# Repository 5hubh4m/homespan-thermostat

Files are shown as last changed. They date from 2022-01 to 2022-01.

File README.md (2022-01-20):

# HomeSpan Thermostat

HomeKit connected smart thermostat based on Arduino using [HomeSpan](https://github.com/HomeSpan/HomeSpan).

## Background and Motivation

I have a 24 V Heat-only system with a 2-wire system (No C wire, only R and W). It used a manual
Honeywell single-point thermostat. I wanted to get the functionalities of a HomeKit compatible
smart thermostat without the hassle of installing a C wire myself and/or having to buy an
expensive smart thermostat. So I created my own with a Wi-Fi capable microcontroller.

## Hardware

I used a [Adafruit ESP32-S2 Feather](https://www.adafruit.com/product/5000) board, along with
a [TMP36](https://www.adafruit.com/product/165) analog temperature sensor, and a
[simple non-latching relay](https://www.adafruit.com/product/4409).

I wired up the TMP36 to an analog input pin (`A5` i.e `8`) and the relay to a digital pin (`10`),
and connected the relay to the R and W wires in my heating panel in the `NO` mode i.e when the relay is
`off`, the heater is also `off`. The circuit diagram is given below.

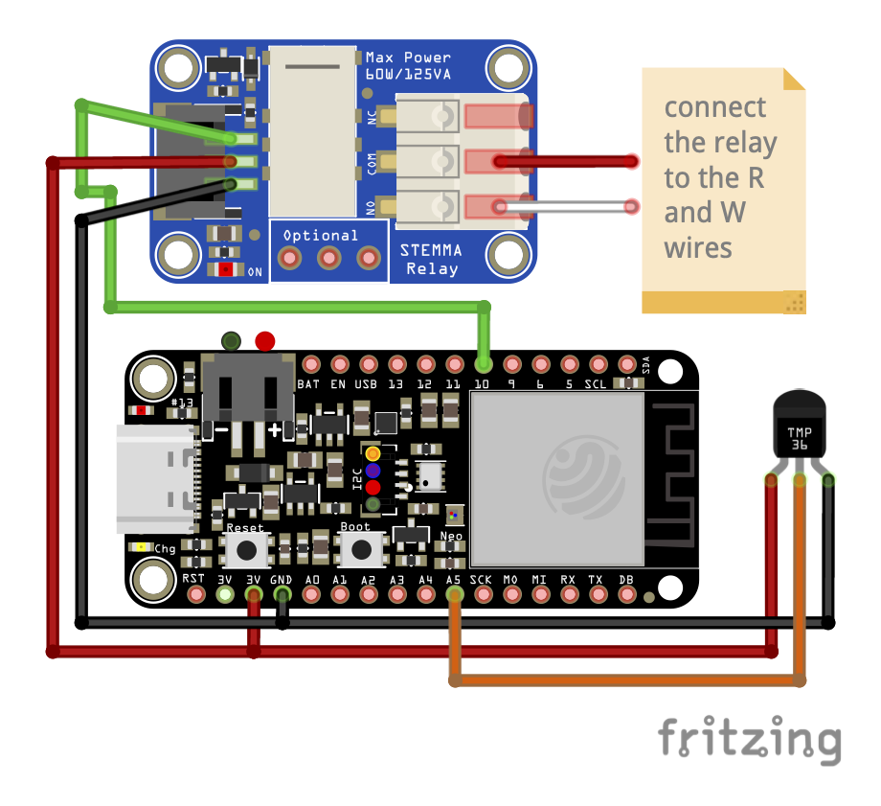
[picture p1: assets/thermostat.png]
This image shows how the components are wired to the microcontroller board. Wiring


## Flashing the Code on the Microcontroller

Use the Arduino IDE to flash the code to the microcontroller. You could also do it using
`arduino-cli` in either serial mode or OTA mode.

```
cd path/to/homespan_thermostat
arduino-cli compile -b esp32:esp32:adafruit_feather_esp32s2 --port PORT_PATH --protocol serial --upload
```

Or

```
cd path/to/homespan_thermostat
arduino-cli compile -b esp32:esp32:adafruit_feather_esp32s2 --port BOARD_IP --protocol network --upload
```

The latter will promt you for the OTA password. The default OTA password for HomeSpan is `homespan-ota`.
It is recommended that you change it in the source code (see below) or using the `O` command of the
[HomeSpan CLI](https://github.com/HomeSpan/HomeSpan/blob/master/docs/CLI.md).

## Configuration and Usage

There are a few parameters that need to be configured.

* The Wi-Fi credentials can be defined in the source code as the macros `WIFI_SSDI`
  and `WIFI_PASSWORD` or can be set using the `W` command of the
  [HomeSpan CLI](https://github.com/HomeSpan/HomeSpan/blob/master/docs/CLI.md).
* The HomeKit pairing code can be defined in the source code as the macro `HOMEKIT_PAIRING_CODE`.
  Otherwise the default code `466-37-726` is used or it can be set using the `S` command of the
  [HomeSpan CLI](https://github.com/HomeSpan/HomeSpan/blob/master/docs/CLI.md).
* The HomeKit QR Setup ID can be defined in the source code as the macro `HOMEKIT_PAIRING_QR_ID`.
  Otherwise the default QR Setup ID `HSPN` is used or it can be set using the `Q` command of the
  [HomeSpan CLI](https://github.com/HomeSpan/HomeSpan/blob/master/docs/CLI.md).
* The OTA Password can be defined in the source code as the macro `DEFAULT_OTA_PASSWORD`.
  Otherwise the default password `homespan-ota` is used or it can be set using the `O` command of the
  [HomeSpan CLI](https://github.com/HomeSpan/HomeSpan/blob/master/docs/CLI.md).

Pair the accessory to HomeKit. The general instructions are given
[here](https://github.com/HomeSpan/HomeSpan/blob/master/docs/HomeSpanUserGuide.pdf). That's pretty much it.

For my particular heating setup, I have enabled two heating modes: _Heating_, and _Auto_. _Heating_ mode allows you to
set a single _Target Temperature_ which the thermostat will try to maintain. However, depending on how well
insulated your home is, and how cold it is outside, it can lead to the heater turning on and off frequently
consuming a lot of energy. _Auto_ mode fixes that by allowing you to set two temperatures, a _Heating Threshold_
and a _Cooling Threshold_. In this mode, the thermostat will only turn on if the temperature reaches below the
_Heating Threshold_, and will provide heat until the _Cooling Threshold_ is reached. This allows the heater to be
on for a longer period of time, but also be turned off for a longer periods of time, which is more energy efficient
than being turned on in bursts.

If you're connected to HomeKit, you should be able to control your heater using Siri.

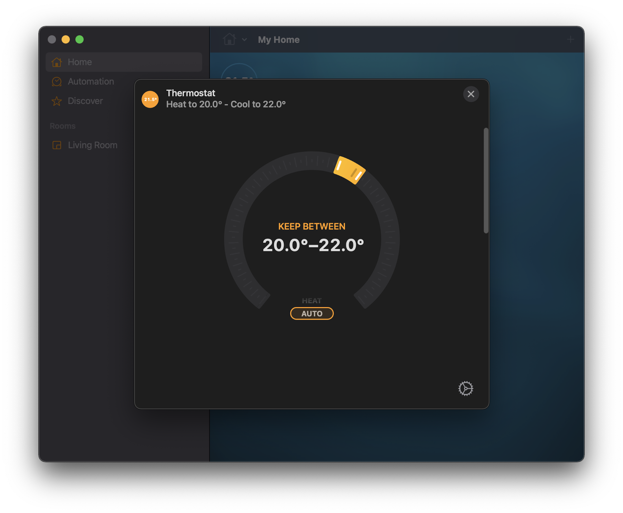
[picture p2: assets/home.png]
This image shows how the this thermostat looks in the Home app. Home


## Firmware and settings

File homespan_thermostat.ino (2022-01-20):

#include <HomeSpan.h>

// define the constants for the thermostat
#define NAME         "Thermostat"
#define MANUFACTURER "Shubham Chaudhary"
#define MODEL        "Thermostat"
#define SERIAL_NUM   "0x0000001"
#define FIRMWARE     "v1.0.0"

// the pin on which the heater relay and
// temperature sensor is connected
#define HEATER_PIN 10
#define TEMP_PIN   8

// constraint the TEMP_PIN to be between 3 and 10
// since we can only use ADC1 as ADC2 is occupied
// during Wi-Fi usage
#if TEMP_PIN < 3 || TEMP_PIN > 10
#error "Temperature sensor MUST be on ADC1 as ADC2 is occupied during Wi-Fi."
#endif

// threshold determines how sensitive
// the heater is to the current temperature
#define TEMP_THRESHOLD 0.5

// number of readings to accumulate before averaging
#define TEMP_READINGS 30

// period to scan for state changes in milliseconds
#define STATUS_PERIOD 2000

// period to scan for temperature in milliseconds
#define SENSE_PERIOD 50

// uncomment these lines to define your own custom parameters
// #define WIFI_SSID             "Your Wi-Fi SSID"
// #define WIFI_PASSWORD         "Your Wi-Fi Password"
// #define HOMEKIT_PAIRING_CODE  "8 Digit Pairing Code"
// #define HOMEKIT_PAIRING_QR_ID "4 Digit Alphanumeric Code"
// #define DEFAULT_OTA_PASSWORD  "Custom OTA Password"

// include the custom classes
#include "include/identify.h"
#include "include/thermostat.h"

// declare the accessories and it's services
static SpanAccessory* accessory;
static SpanService* identifyService;
static SpanService* protocolService;
static SpanService* thermostatService;

void setup() {
  // setup serial
  Serial.begin(115200);

  // setup span device
  homeSpan.enableOTA();
  homeSpan.setStatusPin(LED_BUILTIN);
  homeSpan.setHostNameSuffix("");
  homeSpan.setSketchVersion("1.0.0");

#if defined(WIFI_SSID) && defined(WIFI_PASSWORD)
  // if Wi-Fi credentials are defined, supply
  // them here, otherwise set them using the HomeSpan CLI
  homeSpan.setWifiCredentials(WIFI_SSID, WIFI_PASSWORD);
#endif

#ifdef HOMEKIT_PAIRING_CODE
  // if HomeKit pairing code is defined, supply
  // it here, otherwise the default is used, or
  // can be set using HomeSpan CLI
  homeSpan.setPairingCode(HOMEKIT_PAIRING_CODE);
#endif

#ifdef HOMEKIT_PAIRING_QR_ID
  // if HomeKit QR Code ID is defined, supply
  // it here, otherwise the default is used, or
  // can be set using HomeSpan CLI
  homeSpan.setQRID(HOMEKIT_PAIRING_QR_ID);
#endif

  // start span device
  homeSpan.begin(Category::Thermostats, NAME, NAME, MODEL);

  // initialise span acessory
  accessory = new SpanAccessory();

  // initialise accessory information service
  identifyService = new Identify(NAME, MANUFACTURER, SERIAL_NUM, MODEL, FIRMWARE);

  // intialise the protocol identification service
  protocolService = new ProtocolVersion();

  // initialise thermostat service with the
  // right name, temperature sensor and heater
  // relay pin and in-built NeoPixel as a status LED
  thermostatService = new Thermostat(
    TEMP_PIN,
    HEATER_PIN,
    TEMP_THRESHOLD,
    TEMP_READINGS,
    STATUS_PERIOD,
    SENSE_PERIOD
  );

  // set the thermostat service as primary
  thermostatService->setPrimary();
}

void loop() {
  // run the span IO loop
  homeSpan.poll();
}

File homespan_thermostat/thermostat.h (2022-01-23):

#include <HomeSpan.h>

#include "relay.h"
#include "sensor.h"
#include "neopixel.h"

// enums to define some constants
enum TargetHeaterStates {
  OFF = 0,
  HEAT = 1,
  COOL = 2, // we disable this state since we don't have an AC
  AUTO = 3
};

enum CurrentHeaterStates {
  IDLE = 0,
  HEATING = 1,
  COOLING = 2 // we disable this state since we don't have an AC (in essence this is just a bool)
};

enum TemperatureDisplayUnits {
  CELSIUS = 0,
  FAHRENHEIT = 1 // we disable this state since we are not heathens
};

// class ties the heater relay operation to a characteristic
class CurrentHeaterStatus: public Characteristic::CurrentHeatingCoolingState {
private:
  // heater relay
  Relay heater;

public:
  // constructor for the class
  CurrentHeaterStatus(int heaterPin): Characteristic::CurrentHeatingCoolingState(IDLE), heater(heaterPin) {}

  template <typename T>
  void setVal(T value, bool notify = true) {
    heater.setState(value);
    Characteristic::CurrentHeatingCoolingState::setVal(value, notify);
  }
};

// the class that contains the logic for running the
// thermostat service
class Thermostat: public Service::Thermostat {
private:
  // setup the sensor, heater relay, and status LED
  TemperatureSensor sensor;
  NeoPixel status;

  // temperature threshold, determines the degree
  // to which heater state change is sensitive to
  // current temperature
  const float tempThreshold;

  // alpha for exponential averaging temperature
  const float tempExpAlpha;

  // period in milliseconds before the state is
  // updated and temperature is sensed respectively
  const unsigned long statusUpdatePeriod;
  const unsigned long temperatureSensePeriod;

  // setup the characteristic objects
  CurrentHeaterStatus *currentHeaterState;
  SpanCharacteristic *targetHeaterState;
  SpanCharacteristic *targetTemperature;
  SpanCharacteristic *currentTemperature;
  SpanCharacteristic *temperatureDisplayUnits;
  SpanCharacteristic *heatingThresholdTemperature;
  SpanCharacteristic *coolingThresholdTemperature;

  // track the state of the thermostat
  unsigned long lastUpdateTemperature;
  unsigned long lastSenseTemperature;
  unsigned long lastUpdateState;
  float currentExpAvgTemp;
  bool wasUpdated;

public:
  // constructor for the thermostat
  Thermostat(
    int temp,
    int heater,
    float alpha,
    float threshold,
    unsigned long statePeriod,
    unsigned long sensePeriod
  ):
    sensor(temp),
    tempExpAlpha(alpha),
    tempThreshold(threshold),
    statusUpdatePeriod(statePeriod),
    temperatureSensePeriod(sensePeriod)
  {
    // get an initial reading for current temperature
    currentExpAvgTemp = sensor.readTemp();

    // initialise the status to default
    status.setColor(WHITE);

    // initialise the characteristics
    currentHeaterState = new CurrentHeaterStatus(heater);
    currentTemperature = new Characteristic::CurrentTemperature(currentExpAvgTemp);
    targetHeaterState = new Characteristic::TargetHeatingCoolingState(OFF, true);
    targetTemperature = new Characteristic::TargetTemperature(20, true);
    temperatureDisplayUnits = new Characteristic::TemperatureDisplayUnits(CELSIUS);
    coolingThresholdTemperature = new Characteristic::CoolingThresholdTemperature(24, true);
    heatingThresholdTemperature = new Characteristic::HeatingThresholdTemperature(18, true);

    // setup the valid values for characteristics
    currentHeaterState->setValidValues(2, IDLE, HEATING);
    targetHeaterState->setValidValues(3, OFF, HEAT, AUTO);
    temperatureDisplayUnits->setValidValues(1, CELSIUS);
    temperatureDisplayUnits->removePerms(PW);

    // set the ranges and step values of temperatures
    targetTemperature->setRange(10, 38, 1);
    currentTemperature->setRange(-270, 100, 0.1);
    coolingThresholdTemperature->setRange(10, 35, 1);
    heatingThresholdTemperature->setRange(0, 25, 1);

    // setup the state of the thermostat
    lastUpdateTemperature = millis();
    lastSenseTemperature = millis();
    lastUpdateState = millis();
    wasUpdated = false;
  }

  // mark the state to be updated
  // so the next time loop runs it 
  // doesn't wait for timer period
  virtual bool update() override {
    wasUpdated = targetHeaterState->updated() ||
                 targetTemperature->updated() ||
                 coolingThresholdTemperature->updated() ||
                 heatingThresholdTemperature->updated();
    return true;
  }

  // update the state of the thermostat
  virtual void loop() override {
    // sense temperature every given duration
    if ((millis() - lastSenseTemperature) > temperatureSensePeriod) {
      updateTempReading();
      lastSenseTemperature = millis();
    }

    // update current temperature every given duration
    // but only when when you have enough readings
    if ((millis() - lastUpdateTemperature) > statusUpdatePeriod) {
      updateCurrentTemp();
      lastUpdateTemperature = millis();
    }

    // update state every given duration
    if ((millis() - lastUpdateState) > statusUpdatePeriod || wasUpdated) {
      updateState();
      wasUpdated = false;
      lastUpdateState = millis();
    }
  }
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

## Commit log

2022-01-19 Minor refactor
    [wiring.fzz]
2022-01-20 Multisampling to improve ADC accuracy
2022-01-21 Minor refactor with file names, fixed a threshold bug
    [wiring.fzz]
2022-01-23 Accumulate temperature using exponential averaging instead of averaging
